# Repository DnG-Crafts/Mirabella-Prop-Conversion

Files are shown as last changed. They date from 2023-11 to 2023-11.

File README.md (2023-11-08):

# Mirabella Prop Conversion

## Pop-Up Flashing Tinsel Christmas Tree
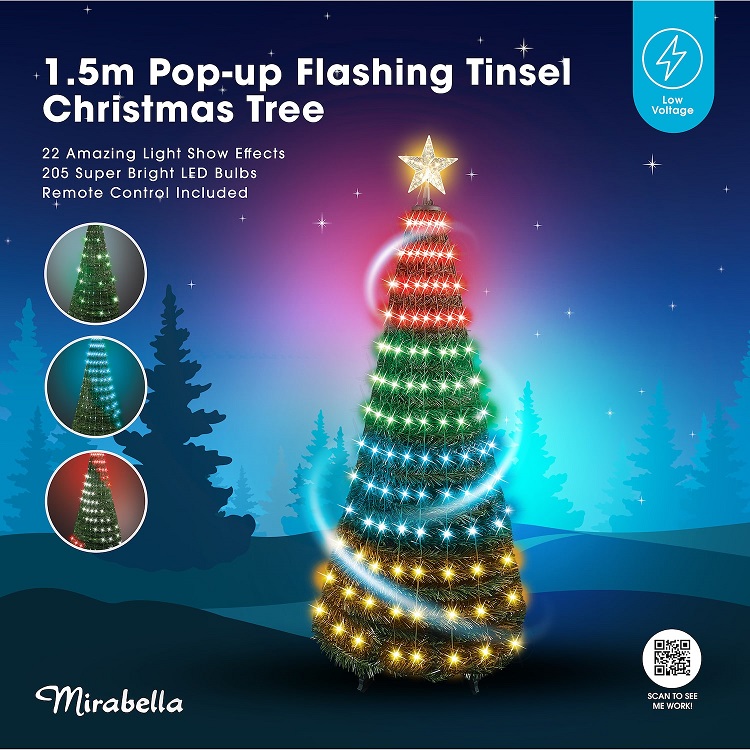
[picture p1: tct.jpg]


## Christmas Light Show Tree
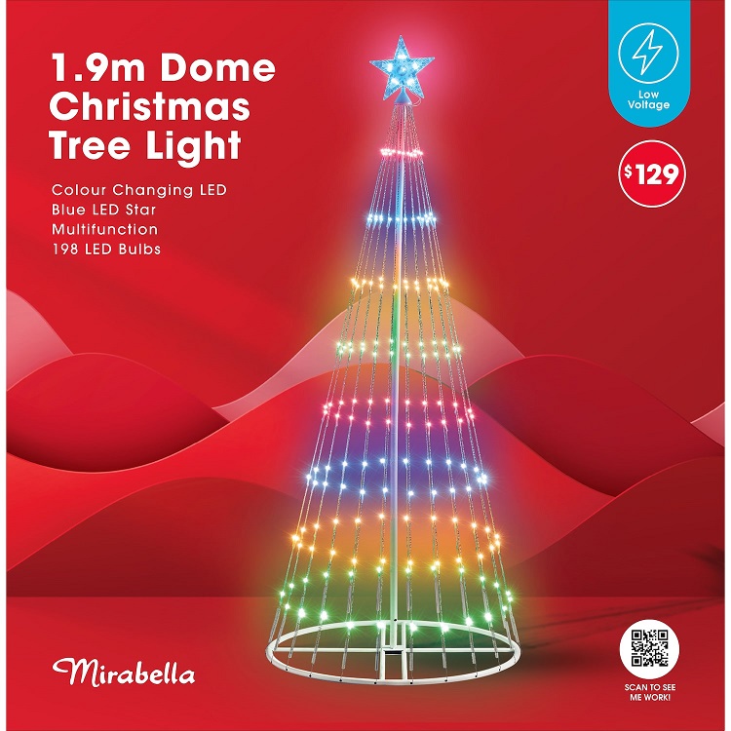
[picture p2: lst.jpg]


## Firework Light
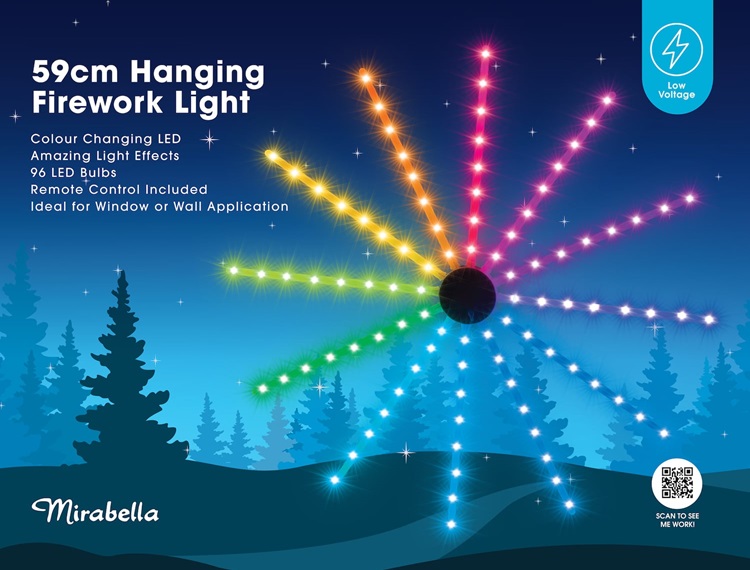
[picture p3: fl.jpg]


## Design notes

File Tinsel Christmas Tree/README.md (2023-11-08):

# Pop-Up Flashing Tinsel Christmas Tree

A fairly easy conversion to wled for the <a href=https://www.mirabella.com.au/mirabella-product-item/pop-up-flashing-tinsel-christmas-tree/>Mirabella 1.5m Light Show Pop-Up LED Dome Tree</a><br>

Each string has 13 pixels, there are 15 strings for a total of 195 pixels each pixel is individually addressable.<br>

The controller has 4 wires that are silkscreened.<br>

<b>+</b>  = 5v<br>
<b>-</b>  = GND<br>
<b>DO</b> = Data Out<br>
<b>L</b>  = GND to Star<br>

The connection to the ESP is simple...<br>
Connect the 5V(+) to the 5V of the esp.<br>
Connect GND(-) to the GND of the esp.<br>
Connect Data Out(DO) to a GPIO of the esp, in my case i used GPIO13.<br>

You could also just use a plug/pigtail to connect it to your ws2811 contoller.

In wled set the GPIO you used, color order is RGB and led count is 195.<br>

If you wish to light the star then connect (L) to the esp GND.<br>

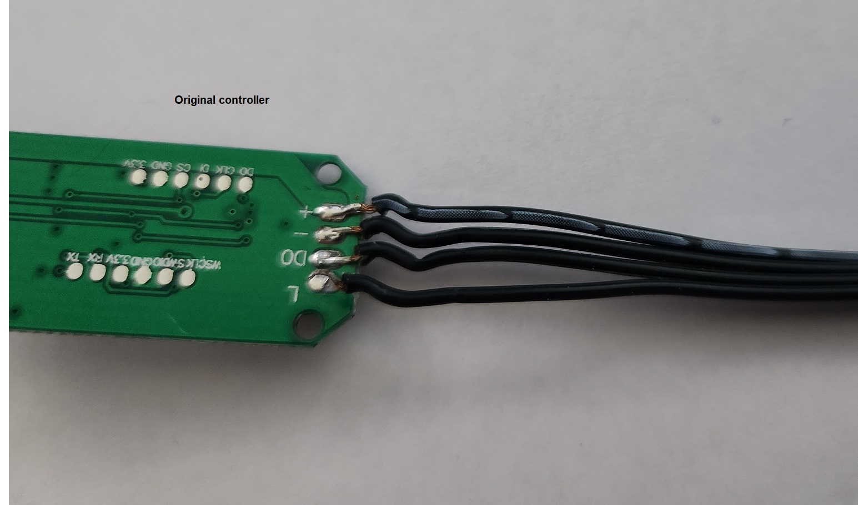
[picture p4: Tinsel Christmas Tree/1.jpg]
<br>
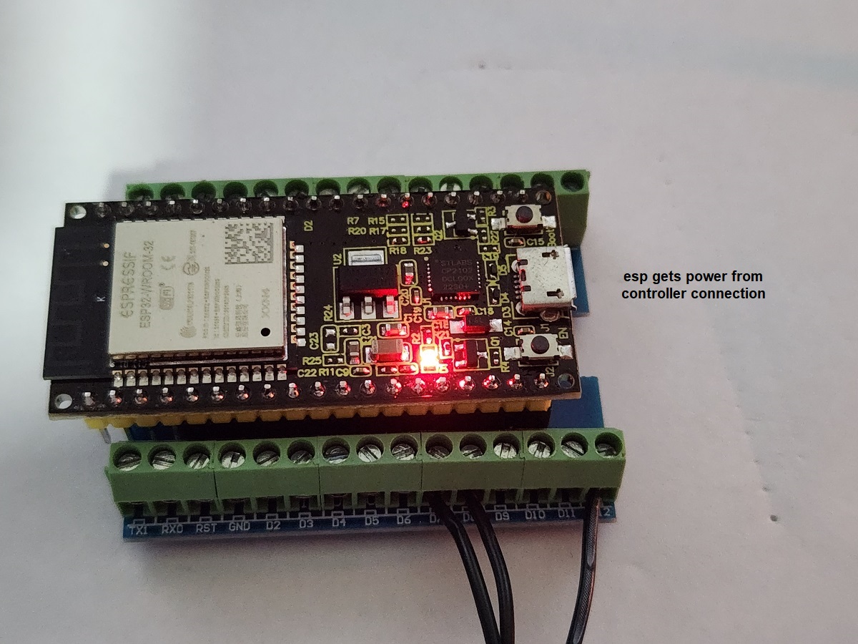
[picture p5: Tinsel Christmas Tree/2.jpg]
<br>
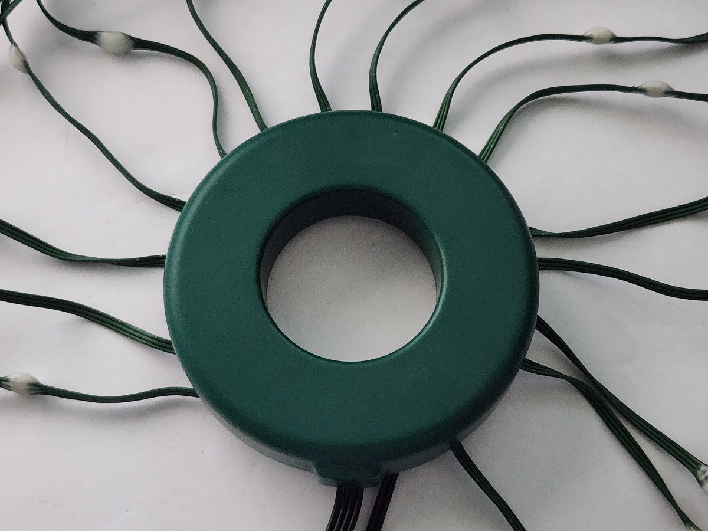
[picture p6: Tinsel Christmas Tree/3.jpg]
<br>
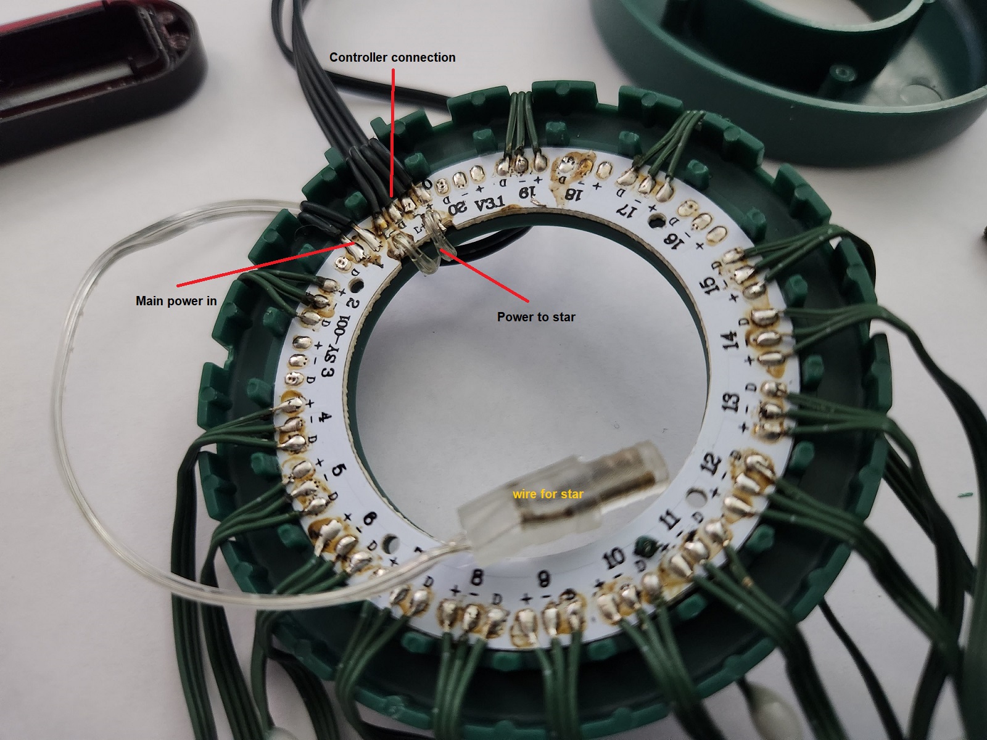
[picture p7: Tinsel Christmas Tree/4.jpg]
<br>
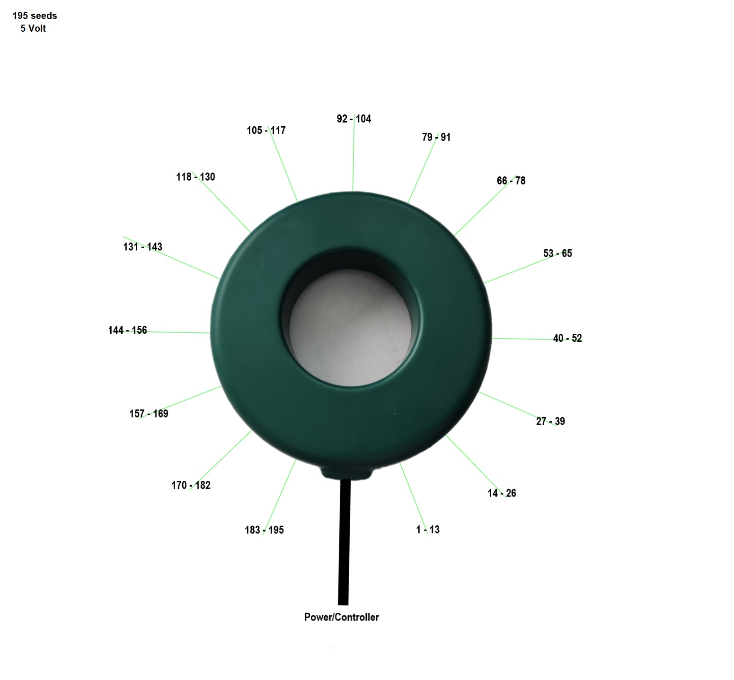
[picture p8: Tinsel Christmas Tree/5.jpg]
<br>

## Star modification

If you wish to add pixels to the star you can repurpose the (L) wire as a data line to the esp, in my case i connected it to GPIO12.<br>
I replaced the leds in the star with 10 seed pixels.<br>

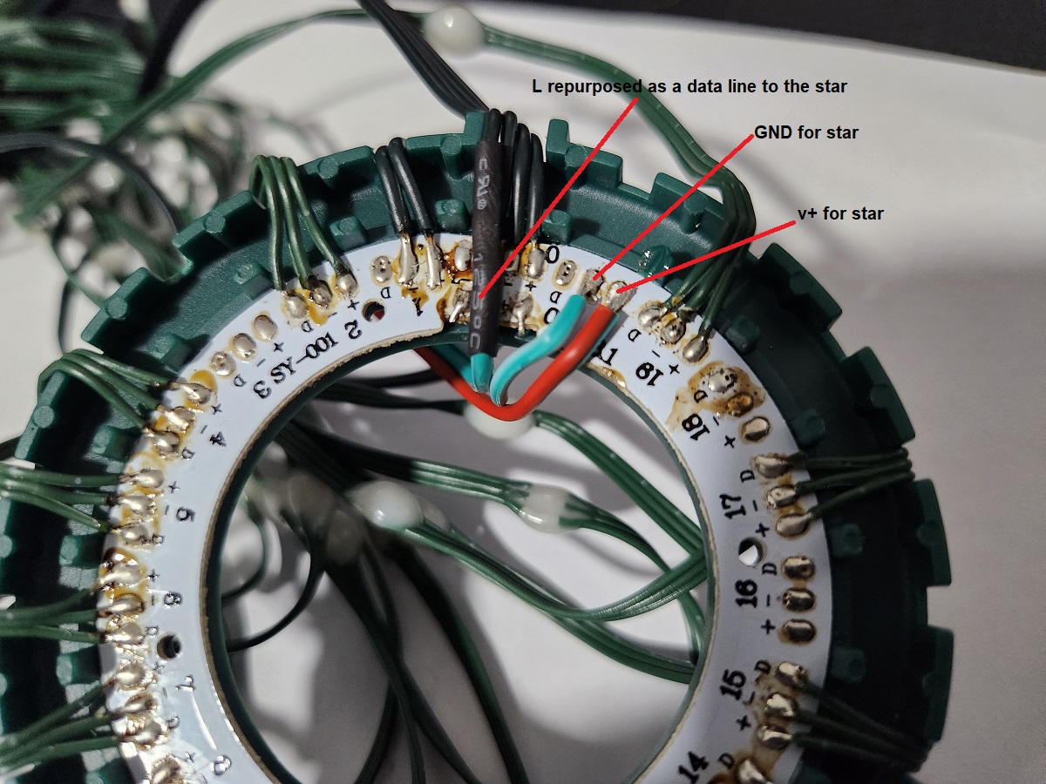
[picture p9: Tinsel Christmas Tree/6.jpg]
<br>
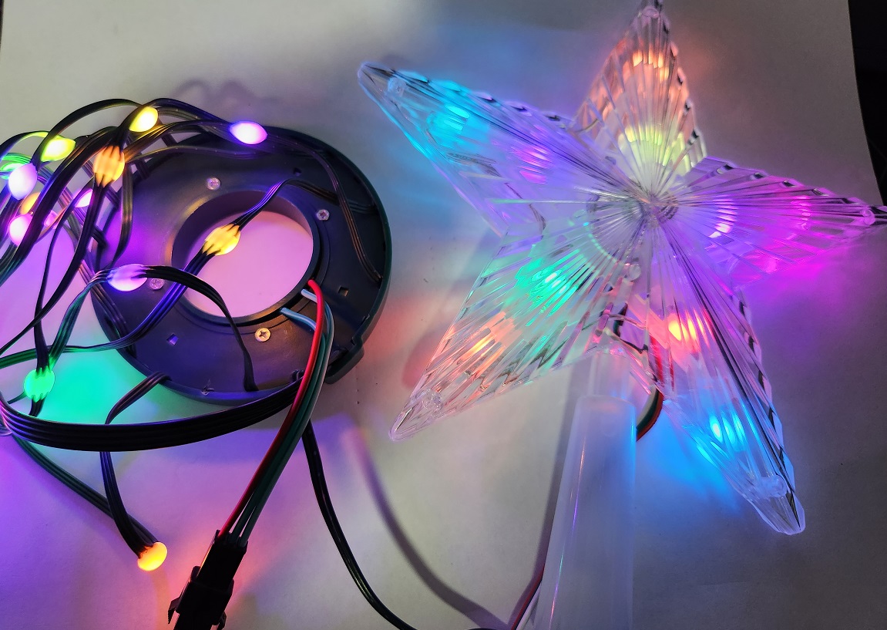
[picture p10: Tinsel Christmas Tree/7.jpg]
<br>

<br>

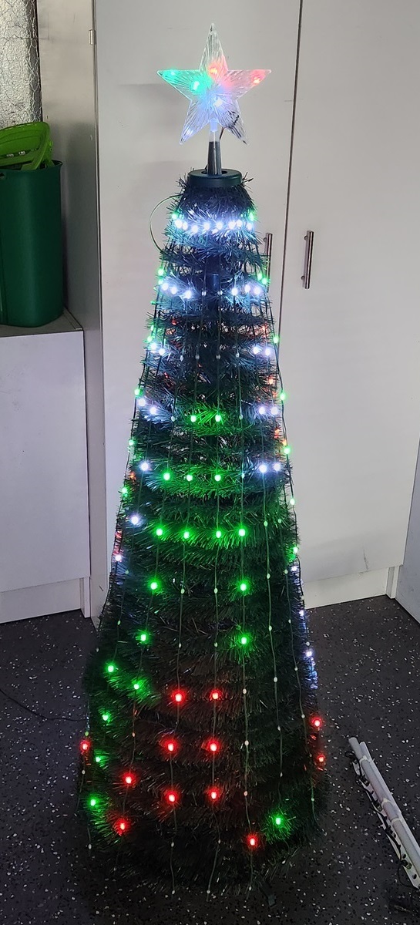
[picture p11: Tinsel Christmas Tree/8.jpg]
<br>

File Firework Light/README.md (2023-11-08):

# Firework Light

A conversion for the <a href=https://www.mirabella.com.au/mirabella-product-item/firework-light/>Firework Light</a><br>

This conversion is pretty simple, you just open the center piece and remove the two chips in the red circles to disable the built in controller and then add a plug/pigtail for a ws2811 controller.

The prop contains 5 volt seed pixels, 8 pixels in each arm with 12 arms for a total of 96 pixels and the xmodel for prop is in this repo.

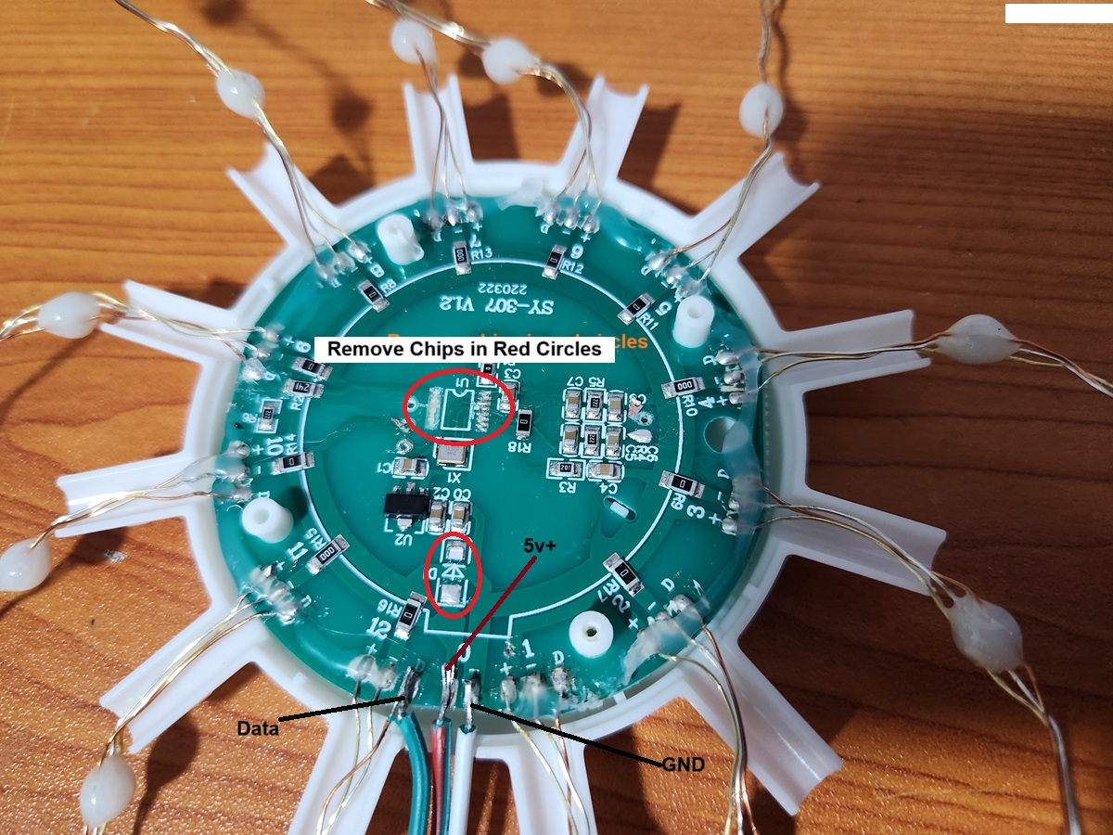
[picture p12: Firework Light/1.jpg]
<br>
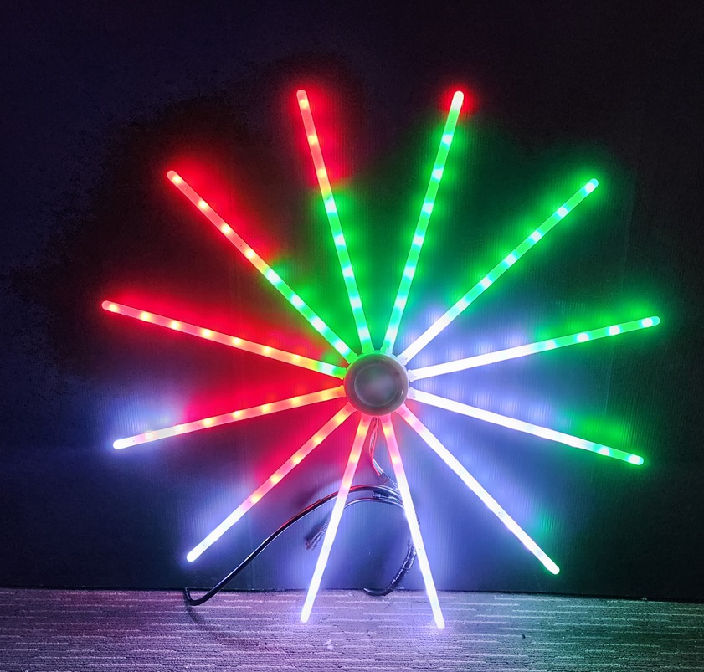
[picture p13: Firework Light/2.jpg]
<br>

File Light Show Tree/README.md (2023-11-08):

# Christmas Light Show Tree

A full seed pixel conversion for the <a href=https://www.mirabella.com.au/mirabella-product-item/christmas-light-show-tree/>Christmas Light Show Tree</a><br>

This prop comes with dumb leds so they need to be replaced with seed pixels.

You use the frame and springs from the prop and 3D print a new topper in PETG using the stl in this repo(supports required)

I used seed pixels with 5cm spacing so it made a total of 816 pixels spread over 2 ports with 408 pixels per port to maintain 40fps if needed.

The xmodel for this tree with 816 pixels is in the repo but you can make one to match your tree in xlights using the round tree model.

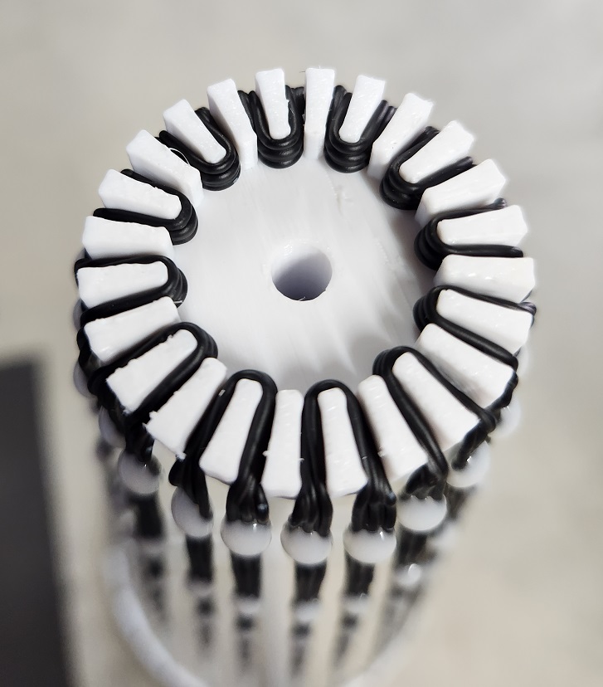
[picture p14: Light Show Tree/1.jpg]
<br>
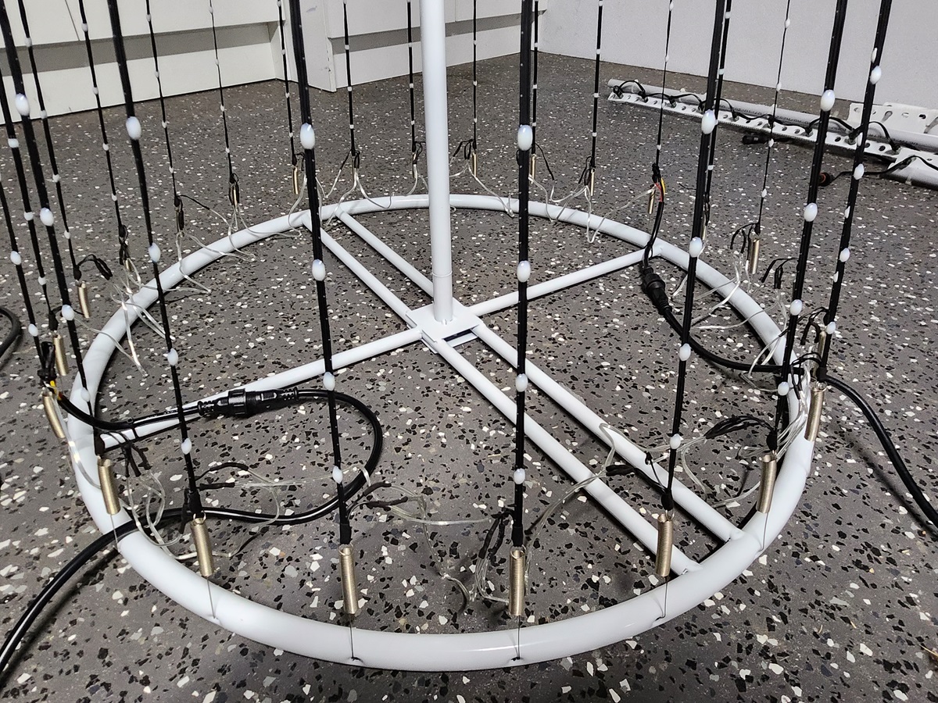
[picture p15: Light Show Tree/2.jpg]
<br>
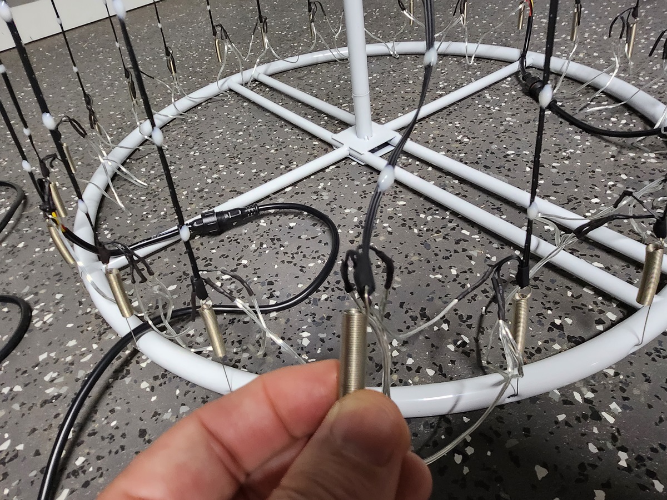
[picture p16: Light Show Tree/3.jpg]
<br>
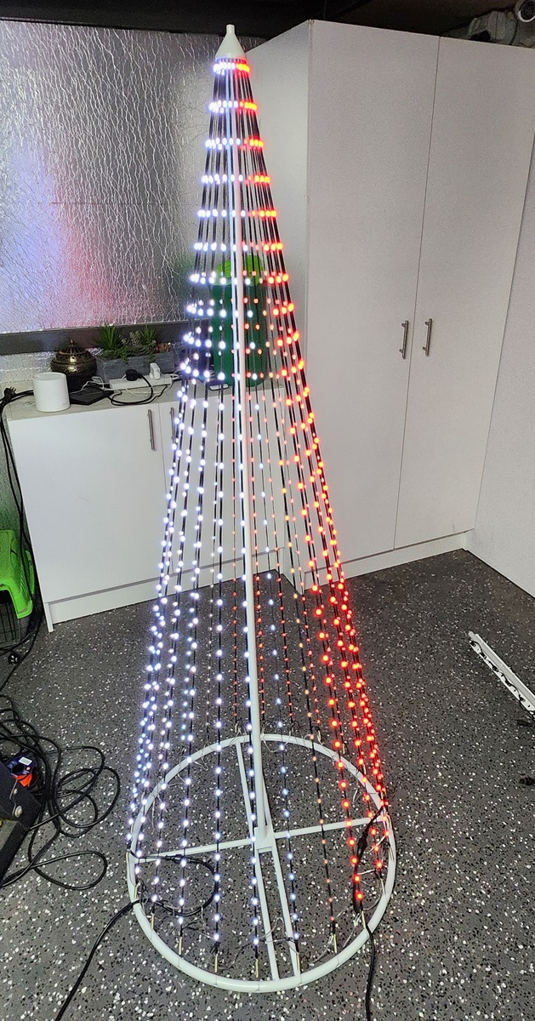
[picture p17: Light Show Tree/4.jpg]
<br>

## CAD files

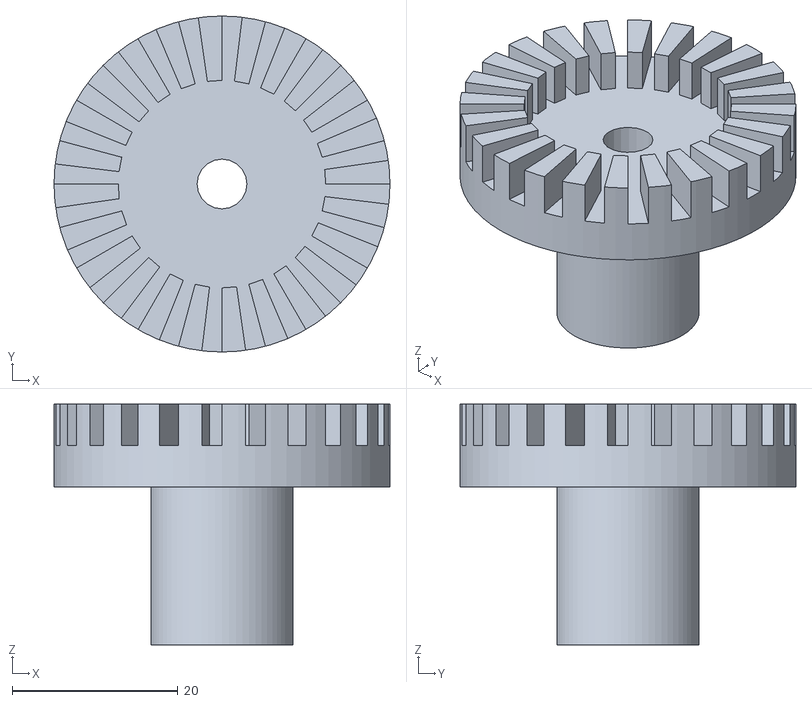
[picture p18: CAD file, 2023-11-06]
Light Show Tree/topper.stl
40.5 x 40.5 x 29.0
